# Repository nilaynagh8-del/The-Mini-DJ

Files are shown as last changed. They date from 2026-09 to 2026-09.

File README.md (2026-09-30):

# The-Mini-DJ
A small, portable, MIDI keyboard to make beats on the go.

*(or just a cooler way to make some beats)* 


---

## Quick Start

1. Download this repo and open the `firmware` folder.
2. Hold **BOOTSEL** and plug in the Pico — a drive called `RPI-RP2` appears.
3. Run `install.ps1` (right-click → Run with PowerShell). It flashes CircuitPython,
   then waits for the `CIRCUITPY` drive and copies all the code on automatically.
34. Plug it back in and make some sound.

---

## Features

- **2 Rotary encoders and button** for parameter adjustments.
- **12 keys** to make beats
- **2 sliders** to make additional parameter adjustments
- **LEDs** for some disco
- **Standalone beat machine** — 16-step sequencer, 6 patterns, runs on battery, no computer
- **3 key layouts** (piano / mirror / drums) with on-screen switching
- **Arpeggiator** with rate & direction controls
- **2 rotary encoders** (pushable) + **2 sliders**, all remappable on the fly
- **1.8" color display** with live view of keys, sliders, and layout
---

## Defaults (if you don't want to change anything):

### Keys for left set:

| Row | Key 1 | Key 2 | Key 3 | 
|---|---|---|---|
| **Top** | PIANO: C3 (48) · MIRROR: C3 · DRUMS: C3 | PIANO: C#3 (49) · MIRROR: D3 · DRUMS: D3  | PIANO: D3 (50) · MIRROR: E3 · DRUMS: E3 |
| **Bottom** | PIANO: D#3 (51) · MIRROR: F3 · DRUMS: F3 | PIANO: E3 (52) · MIRROR: G3 · DRUMS: G3  | PIANO: F3 (53) · MIRROR: A3 · DRUMS: A3 |

### Keys for right set:

| Row | Key 1 | Key 2 |
|---|---|---|
| **Row 1**  | PIANO: F#3 (54) · MIRROR: C4 · DRUMS: Kick (36, ch10) | PIANO: G3 (55) · MIRROR: D4 · DRUMS: Snare (38, ch10)  | 
| **Row 2**  | PIANO: G#3 (56) · MIRROR: E4 · DRUMS: Closed Hat (42, ch10) | PIANO: A3 (57) · MIRROR: F4 · DRUMS: Open Hat (46, ch10) |
| **Row 3**  | PIANO: A#3 (58) · MIRROR: G4 · DRUMS: Clap (39, ch10) | PIANO: B3 (59) · MIRROR: A4 · DRUMS: Tom (45, ch10) | 

### Left Encoder:

- **Rotate** → Octave shift (−2 to +6, shown on screen)
- **Push ×1** → Panic / all-notes-off
- **Push ×2** → Enter Beat Mode (standalone drum machine)
- **Push ×3** → Arpeggiator page (hold keys + it plays them for you)
- In Beat Mode: rotate = step cursor · hold + rotate = switch pattern A–F · hold 600 ms = clear pattern · tap = exit & save

### Right Encoder:

- **Rotate** → Sends the selected MIDI CC (default: CC 74 filter cutoff)
- **Push ×1** → Cycle CC target: Cutoff (74) → Mod (1) → Volume (7) → Expression (11) → Reverb (91)
- **Push ×2** → CC Remap page (move a slider to reassign its CC)
- **Push ×3** → Switch key layout (screen animation confirms)
- In Beat Mode: rotate = BPM (40–220) · push = play/stop

### Bottom Slider:

- **Slide** → CC 1 (Mod Wheel) by default — remappable to any CC 0–127 via the remap page. In Beat Mode: BPM macro.

### Top Slider:

- **Slide** → CC 7 (Channel Volume) by default — remappable. In Beat Mode: headphone/output volume.

---

## What is this?

This is a MIDI keyboard I made to get into music production. This device can make all kinds of music. You can make various beats, change up different audio affects, and more!

## How it works and Issues I Faced

The Raspberry Pi Pico is placed on the bottom of the PCB along with the switch, battery charging module, battery, and the DAC. The rest of the components are on the top. This MIDI keyboard is running **Circuit python** and uses many different libraries to make the various parts work. Pretty obvious, but it uses the keys use a matrix layout.

When I was designing the PCB I wanted to make this MIDI keyboard as versatile and portable as possible. I also wanted to make it look clean and sleek. I had to reposition the components several times before I was satisfied. I also spent quite some time in CAD designing this case as I wanted to make it as clean as possible. It took me quite some while to find the right shape and and size without making it look awkward. It was quite a challenge connecting all the desired components to the Pi Pico as it only had so many pins. I ended up having to interpret different methods to save pins.

## How to use in detail

Flash the firmware with install.ps1 (hold BOOTSEL while plugging in when prompted), then plug into any DAW — it appears as a standard USB MIDI keyboard and the 12 keys play notes immediately (velocity fixed at 100; the PCB has no velocity sensing). The screen shows a live view: layout name, octave, keys lighting up as you press, slider positions, encoder values, and arpeggiator status. The left encoder shifts octave (−2…+6), single-push is a panic button, double-push enters the standalone beat machine (6 synthesized drums over the I2S header into a PCM5102 — 16-step sequencer, 6 pattern slots, finger-drumming on the left keys, all persisted to flash, runs from battery with no computer), and triple-push opens the arpeggiator (rate 1/4–1/16, up/down/updown). The right encoder is an assignable macro control — single-push cycles what it sends (cutoff → mod → volume → expression → reverb), double-push opens the CC remap page where moving a slider live-reassigns which CC it transmits, and triple-push switches the key layout (PIANO chromatic run / MIRROR octaves / DRUMS + GM drum map) with a full-screen animation. Every setting — layout, octave, CC assignments, arp config, beats, BPM — saves to flash automatically and survives power-off. To adjust behavior, edit lib/md_kbd/config.py (pins, CC targets, debounce, slider deadband, screen offsets) and lib/md_kbd/layouts.py (base note, key→note maps, LED order), save to the CIRCUITPY drive, and it reboots with your changes; the serial console at code.circuitpython.org shows any errors.

---

## BOM

- 1x Raspberry PI Pico with headers
- 14x through-hole 1N4148 Diodes
- 12x MX-Style switches
- 2x EC11 Rotary encoder
- 1.8 Inch TFT LCD Screen Display *(GND, VCC, SCL, SDA, RES, DC, CS, BL)*
- 12x blank DSA keycaps
- 4x M3x11mm screws
- Adafruit PCM5100 I2S DAC breakout
- 14x SK6812MINI-E mini LEDs
- 2x Bourns PTA2043-2210DPB103 slide potentometer
- TP4056 Type-c USB Battery Charger Module
- 3000 MAH lipo 1s battery
- SS12D00 Mini Slide Switch

| Parts | Price |
|---|---|
| **1x [Raspberry PI Pico with headers](https://www.sparkfun.com/raspberry-pi-pico-2-with-headers.html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)**  | $6.60 |
| **14x [through-hole 1N4148 Diodes](https://www.sparkfun.com/diode-small-signal-1n4148.html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)**  |$3.50 |
| **12x [MX-Style switches](https://www.amazon.com/GATERON-Yellow-Keyboard-Switches-Mechanical/dp/B0DYJVRB46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)**  | $9.99 |
| **2x [EC11 Rotary encoder](https://www.sparkfun.com/rotary-encoder-illuminated-rgb.html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)**  | $9.90 |
| **1x [1.8 Inch TFT LCD Screen Display *(GND, VCC, SCL, SDA, RES, DC, CS, BL)](https://www.amazon.com/JESSINIE-Display-Arduino-128x160-Interface/dp/B0D31BGJWF)**  | $9.95 |
| **12x [blank DSA keycaps](https://www.sparkfun.com/cherry-mx-keycap-r2-opaque-black.html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)**  | $12.6 |
| **2x [Bourns PTA2043-2210DPB103 slide potentometer](https://www.mouser.com/ProductDetail/Bourns/PTA2043-2210DPB103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)**  | $3.92 |
| **1x [TP4056 Type-c USB Battery Charger Module](https://www.amazon.com/TP4056-Lithium-Charging-Protection-Functions/dp/B0G2S8478G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)**  | $3.90 |
| **1x [3000 MAH lipo 1s battery](https://www.amazon.com/JLJLUP-Rechargeable-Integrated-Protection-Development/dp/B0FH9XHXRT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)**  | $9.99 |
| **1x [SS12D00 Mini Slide Switch](https://www.sparkfun.com/spdt-slide-switch.html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)**  | $0.95 |
| **Total not including PCB or 3d prints:** | **$71.30** |

---

## Renders/Images






---

## Credits

Big shout out to **Hack Club** for giving me the opportunity to make this macropad. I would also like to thank [Logan Peterson](https://github.com/SharKingStudios/SplashPad/tree/main), as I modeled my readme.md after his hackpad's since I was amazed by how well written it was.

---

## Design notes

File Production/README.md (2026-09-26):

# MIDI Keyboard Firmware (CircuitPython 10.3.1)

Firmware for the custom 12-key MIDI keyboard PCB (RP2040 / Raspberry Pi Pico).
USB MIDI controller **and** a standalone pocket beat machine.

## What it does

| Control | Function |
|---|---|
| **12 keys** | Play notes (velocity fixed at 100). Three layouts, switch by **triple-pressing the right encoder**: PIANO / MIRROR / DRUMS |
| **Left encoder** | Turn = octave shift (−2…+6). Push = panic (all notes off). **Double-push = arpeggiator page** |
| **Right encoder** | Turn = assignable CC (cycles CUTOFF→MOD→VOLUME→EXPRESSION→REVERB on single push). **Double-push = CC remap page** |
| **Right encoder triple push** | Switch key layout (screen animation confirms) |
| **Bottom slider (RV1)** | CC 1 (mod wheel) by default, remappable |
| **Top slider (RV2)** | CC 7 (channel volume) by default, remappable |
| **Encoder pushes** | Both wired into the key matrix — they also light their SK6812 LEDs |
| **14× SK6812** | Keys glow while held (hue = note), sliders mirror position, encoders show value |
| **240×240 LCD** | Live view: layout, octave, key grid lighting up, slider bars, encoder values, arp status, USB status |

Layouts:
- **PIANO** — continuous chromatic run starting at C3 (MIDI 48), left block then right block
- **MIRROR** — right block repeats the left block one octave up (great for octave stabs)
- **DRUMS** — left block notes, right block General MIDI drum map on channel 10

Everything (layout, octave, CC assignments, arp settings) **saves to flash** automatically when you leave a settings page — survives power-off.

## Install (one click)

1. Double-click `install.ps1` (or right-click → Run with PowerShell)
2. Follow the prompts: unplug, hold **BOOTSEL**, replug, release
3. The script flashes CircuitPython and copies everything to `CIRCUITPY`
4. Done — your keyboard appears as a USB MIDI device

The script can be re-run anytime to update the firmware files (skip to the CIRCUITPY step — CircuitPython is already installed).

## Manual install

1. Hold BOOTSEL while plugging in USB → `RPI-RP2` drive appears
2. Drag `firmware/adafruit-circuitpython-raspberry_pi_pico-en_US-10.3.1.uf2` onto it
3. Board reboots as `CIRCUITPY`
4. Copy `lib/`, `code.py`, `boot.py` from this folder onto `CIRCUITPY`

## Playing it

- Plug into any DAW (Ableton, FL, GarageBand…) — it shows up as a standard USB MIDI keyboard
- Hold keys and use the DAW's learn function to map the sliders/encoders
- **Arpeggiator**: triple-push the *left* encoder. L-enc selects ON/OFF, RATE, MODE; R-enc changes the selected value; right-push exits (and saves)

## 🥁 Beat mode (standalone, no computer)

Turn your keyboard into a pocket drum machine: 6 synthesized drums through
the I2S header → PCM5102 DAC → headphones.

| Gesture | Action |
|---|---|
| **Double-push LEFT encoder** | Enter/exit beat mode |
| Right-block keys (6) | Toggle drum hit at the step cursor (and audition it) |
| Left-block keys (6) | Whack the drums live, finger-drumming style |
| Left encoder | Move the step cursor (1-16) |
| Right encoder | BPM 40-220 |
| Bottom slider | BPM macro |
| Top slider | Output volume |
| Right-encoder push | Play / stop |
| Left-encoder tap | Exit beat mode (saves) |
| Left-encoder hold 600 ms | Clear current pattern |

6 pattern slots (A-F) × 16 steps × 6 lanes, all saved to flash. Step cursor
is the yellow column; the white column sweeping is the playhead.

## 🔋 Battery power

You need: a 3.7 V LiPo/Li-Ion (or 4×AA pack, 4.5-5.5 V) + a small slide
switch + a PCM5102 DAC module (~$3).

Wiring:
- Battery **+** → one leg of the switch → Pico **VSYS** (pin 39)
- Battery **–** → Pico **GND** (pin 38)
- PCM5102: **VIN→3V3 (pin 36)**, **GND→GND**, **BCK→GP15**, **LRCK/LCK→GP16**, **DIN→GP17**, **SCK→GND** (tie the SCK jumper on the module), **3.3V logic jumper open**
- Headphones: 3.5mm jack on the PCM5102 module's L/R/G

USB and battery can both be connected — the Pico's power path IC handles it
(USB wins when present). The switch simply disconnects the battery.

Beat mode lazily initializes audio the first time you use it, so MIDI-only
sessions pay zero memory cost.

## Tuning / troubleshooting

| Symptom | Fix |
|---|---|
| Screen shows shifted/mirrored image | Edit `LCD_X_OFFSET` / `LCD_Y_OFFSET` in `lib/md_kbd/config.py`, or set MADCTL rotation (see lcd.py) |
| Screen stays black | Check LCD solder joints; try lowering `LCD_SM_FREQ` in config.py (e.g. `31_250_000`) |
| Wrong key plays | Swap entries in `HW_BITS` in `lib/md_kbd/layouts.py` |
| LED #N lights the wrong key | Swap entries in `LED_CHAIN2KEY` in `layouts.py` |
| Encoder counts backwards | Swap the A/B pin numbers in `config.py` (`ENC_*_A` / `ENC_*_B`) |
| Slider jitters | Raise `SLIDER_DEADBAND` in config.py |
| Serial console | `code.circuitpython.org` in a browser, or Mu editor — errors print there |

## Source layout

```
code.py                    entry point
boot.py                    USB bring-up (kept minimal)
lib/md_kbd/
  config.py                pins, timing, CC targets (from your KiCad netlist)
  layouts.py               key layouts + hardware-bit ↔ physical mapping
  matrix.py                2×7 debounced matrix scan
  encoders.py              rotaryio quadrature readers
  sliders.py               oversampled ADC with hysteresis
  leds.py                  SK6812 patterns
  lcd.py                   ST7789 driver (PIO-SPI) + framebuffer + 5×7 font
  ui.py                    all screen pages + layout animation
  arp.py                   arpeggiator engine
  midi_io.py               USB MIDI packet sender
  settings.py              flash-persisted settings (NVM)
  app.py                   main state machine
```

## Future: standalone synth

The PCB has an I2S header (GP15/16/17) ready for a PCM5102 DAC module. That's a v2 feature — sound generator so the keyboard makes noise with no computer attached.

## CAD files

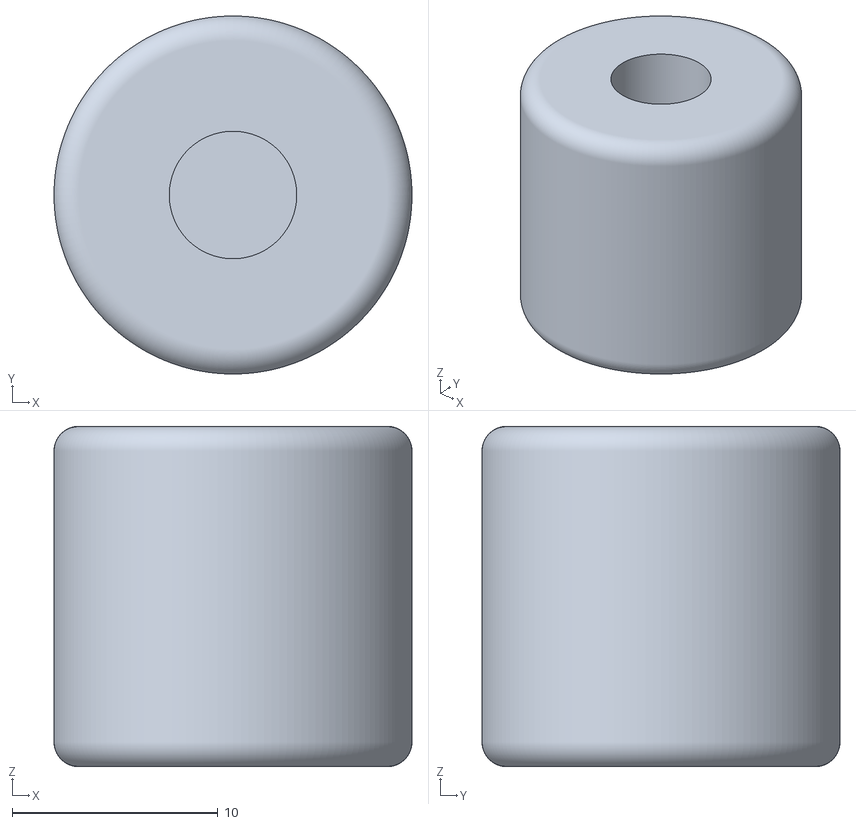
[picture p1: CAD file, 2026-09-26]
Production/Knob (1).stl
17.4 x 17.4 x 16.6

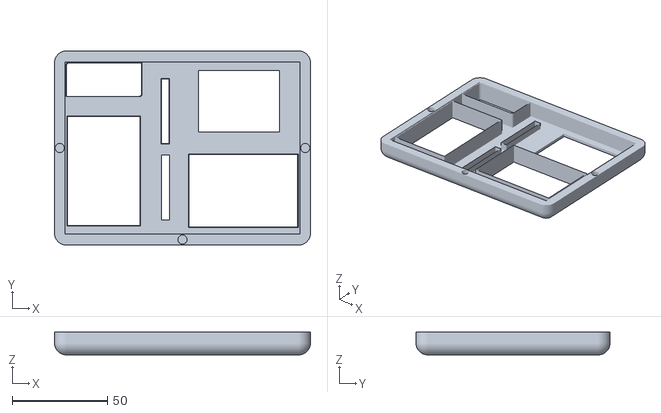
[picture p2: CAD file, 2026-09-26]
Production/Top Case.stl
134.5 x 102.0 x 12.0

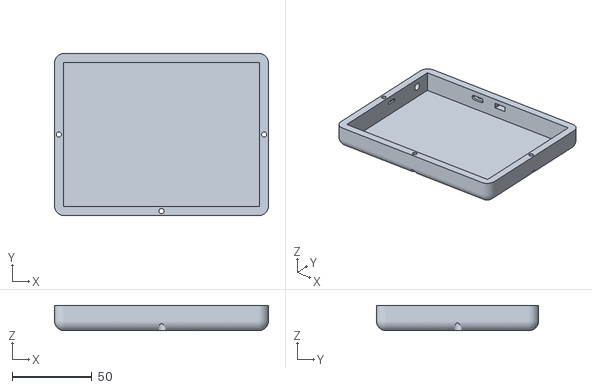
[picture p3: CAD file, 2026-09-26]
Production/Bottom Case.stl
134.5 x 102.0 x 16.0

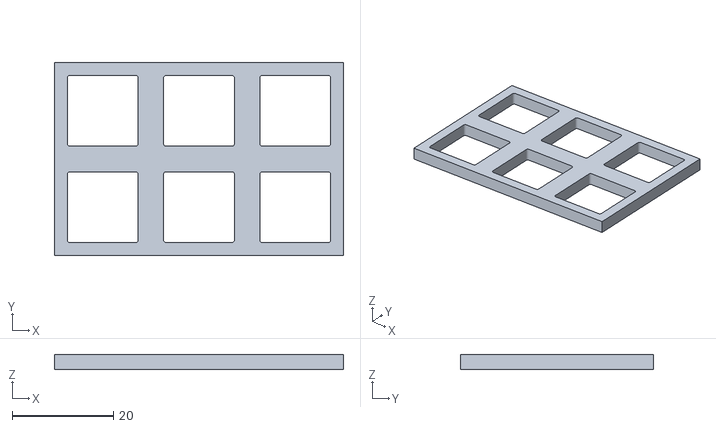
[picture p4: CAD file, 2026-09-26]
Production/Key Plates.stl
57.1 x 38.1 x 3.00

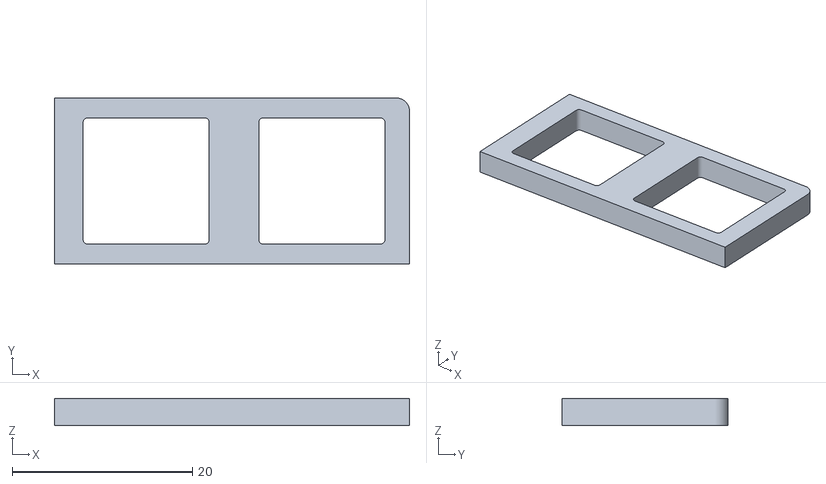
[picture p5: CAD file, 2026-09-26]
Production/Rotary Knobs Plate.stl
39.4 x 18.4 x 3.00

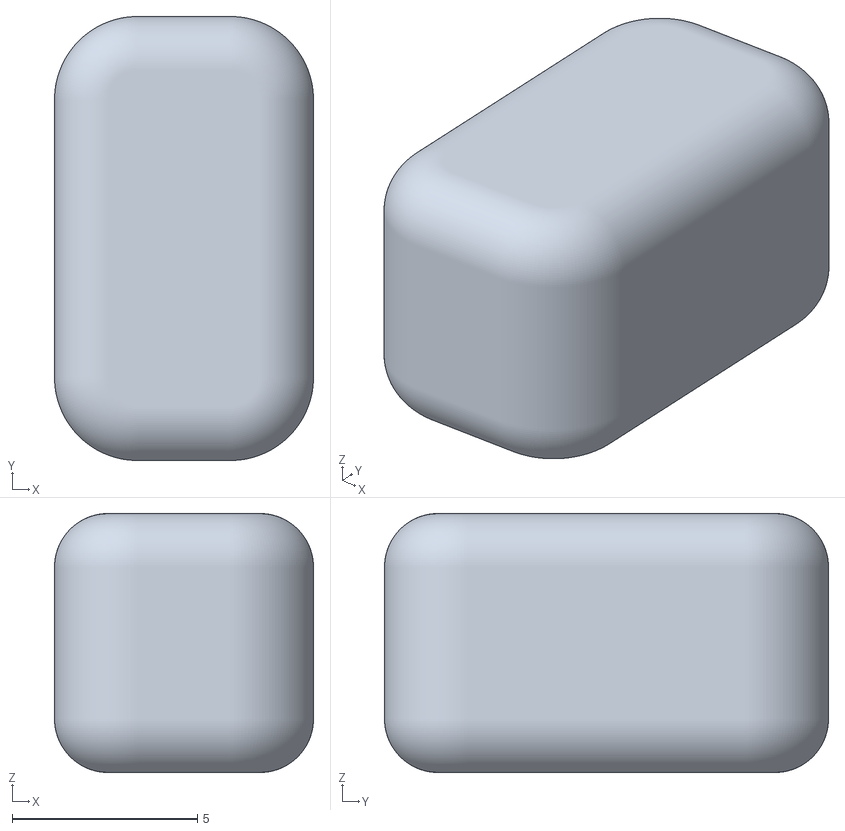
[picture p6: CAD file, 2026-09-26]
Production/Slider tab.stl
7.00 x 12.0 x 7.00

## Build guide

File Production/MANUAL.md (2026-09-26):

# MIDI Keyboard — Complete Manual

*How everything works and how to use it. Written for someone who has never
touched MIDI before.*

---

## Table of Contents

1. [What you built](#1-what-you-built)
2. [MIDI in 5 minutes](#2-midi-in-5-minutes)
3. [Installing the firmware](#3-installing-the-firmware)
4. [Powering the keyboard](#4-powering-the-keyboard)
5. [Using it — Performance mode](#5-using-it--performance-mode)
6. [Using it — Settings pages](#6-using-it--settings-pages)
7. [Using it — Beat mode (standalone drums)](#7-using-it--beat-mode-standalone-drums)
8. [How the code works](#8-how-the-code-works)
9. [Hardware reference — how the PCB works](#9-hardware-reference--how-the-pcb-works)
10. [Customizing](#10-customizing)
11. [Troubleshooting](#11-troubleshooting)

---

## 1. What you built

A 12-key USB MIDI controller **and** standalone drum machine:

| Part | What it is |
|---|---|
| 12 mechanical keys | Play notes (or drums) |
| 2 rotary encoders (left, right) | Turn = adjust · push = button (with tap/double/triple press) |
| 2 sliders (bottom RV1, top RV2) | Analog control of any MIDI CC |
| 240×240 color LCD | Live status: notes, sliders, encoders, playhead |
| 14 RGB LEDs | Under-key glow + 2 encoder LEDs |
| I2S header (J2) | Where the PCM5102 DAC plugs in for beat mode |
| Pico (RP2040) | The brain, runs CircuitPython |

Two power sources: **USB** (data + power) or **battery** (power only, via
your switch into VSYS). Both at once is fine — USB wins.

---

## 2. MIDI in 5 minutes

MIDI is just small text-like messages sent over USB. The ones this keyboard
sends:

| Message | Meaning | When we send it |
|---|---|---|
| **Note On** (note number, velocity) | "a key went down" | You press a key. Note 60 = middle C. Velocity = how hard (ours is fixed 100) |
| **Note Off** | "key came up" | You release |
| **Control Change** (CC#, value 0–127) | "a knob/slider moved" | You turn an encoder or move a slider. CC 1 = mod wheel, CC 7 = volume, CC 74 = filter cutoff — these are standard numbers synths already understand |
| **CC 123, value 0** | "all notes off" (panic) | Left-encoder single push |

Your DAW (Ableton, FL Studio, GarageBand, Reaper…) receives these and makes
sound with whatever instrument is selected. **The keyboard makes no sound by
itself** — it's a controller. Except in beat mode, where it synthesizes its
own drums.

---

## 3. Installing the firmware

### Easy way

1. Plug the Pico in (it's the big chip on your PCB — it's a Raspberry Pi Pico module).
2. Double-click `install.ps1` → "Run with PowerShell".
3. When it says so: unplug, **hold the BOOTSEL button**, plug back in, release.
4. Wait. Done.

The installer flashes CircuitPython (the interpreter) once, then copies the
firmware files. To update your own edits later, re-run it — the flash step
is skipped since CircuitPython is already on the chip.

### Manual way

1. Hold **BOOTSEL**, plug in USB, release → a drive `RPI-RP2` appears.
2. Drag `firmware/adafruit-circuitpython-raspberry_pi_pico-en_US-10.3.1.uf2` onto it.
3. Board reboots as `CIRCUITPY`.
4. Copy `code.py`, `boot.py`, and the `lib/` folder onto `CIRCUITPY`.

### Seeing errors

Open [code.circuitpython.org](https://code.circuitpython.org) in Chrome/Edge,
click "Serial" — or use the Mu editor. If something's wrong with the code,
the error prints there.

---

## 4. Powering the keyboard

### USB only (no battery needed)

Everything works, including beat mode if a DAC is connected.

### Battery + switch (portable)

You need: 3.7 V LiPo/Li-Ion or 4×AA pack (4.5–5.5 V), any small slide
switch, optional PCM5102 DAC for sound.

```
Battery (+) ──► switch ──► Pico VSYS (physical pin 39, back row)
Battery (–) ─────────────► Pico GND  (physical pin 38)
```

- Flip the switch → keyboard boots, octave LEDs flash, screen shows "MIDI".
- Plugging USB while the switch is on: safe, USB takes over.
- **Never** connect a battery straight to the 3V3 pin — VSYS only.

### Sound for beat mode (PCM5102, ~$3)

```
PCM5102   →   Pico
VIN       →   3V3  (pin 36)
GND       →   GND
BCK       →   GP15
LCK       →   GP16
DIN       →   GP17
SCK       →   GND  (also solder the SCK jumper pad on the module)
```

Headphones plug into the DAC module's own 3.5 mm jack. Volume is the top
slider while in beat mode.

---

## 5. Using it — Performance mode

This is the main screen after boot. Just play.

### Keys

Press → note plays, key lights up on the screen grid and on the PCB's LED.
Release → stops. You can hold as many as you want (N-key rollover).

**Three layouts** — switch with **triple-push of the right encoder** (screen
bursts a ring animation + name):

| Layout | Left block (6 keys) | Right block (6 keys) |
|---|---|---|
| **PIANO** | C3, D3, E3, F3, G3, A3 … continues chromatically → | …A#3 up to G#4 |
| **MIRROR** | C3 D3 E3 F3 G3 A3 | same + one octave up |
| **DRUMS** | notes C3–A3 | GM drum map (channel 10): kick, snare, hats, etc. |

### Left encoder

| Gesture | Action |
|---|---|
| Turn | Octave shift −2…+6 (shown top-left of screen) |
| Push ×1 | **Panic** — all notes off (red LED flash) |
| Push ×2 | Enter **beat mode** |
| Push ×3 | Enter **arpeggiator page** |

### Right encoder

| Gesture | Action |
|---|---|
| Turn | Sends the selected CC (default CC 74 cutoff) |
| Push ×1 | Cycle which CC it controls: CUTOFF → MOD → VOLUME → EXPR → REVERB |
| Push ×2 | Enter **CC remap page** |
| Push ×3 | Switch layout (PIANO → MIRROR → DRUMS) |

### Sliders

- Bottom (RV1) = **CC 1, mod wheel**
- Top (RV2) = **CC 7, channel volume**

The DAW responds automatically — no mapping needed for these two.

---

## 6. Using it — Settings pages

### CC Remap page (double-push RIGHT encoder)

Screen shows both sliders with their current CC number. **Move a slider** —
it now sends that number as you drag? No: moving a slider *changes* which CC
it sends (the number follows your position 0–127, pick one you like, e.g.
CC 74 for cutoff, CC 71 for resonance, CC 2 for breath). **Push right
encoder** to save and go back. Everything is stored in flash and remembered
after power-off.

### Arpeggiator page (triple-push LEFT encoder)

Hold some keys, and the arp plays them as a repeating pattern for you.

| Row | Turn RIGHT encoder to change |
|---|---|
| ON/OFF | enable/disable |
| RATE | 1/4, 1/8, 1/8T (triplet), 1/16 |
| MODE | UP, DOWN, UPDOWN |
| EXIT | — (or just push RIGHT encoder) |

LEFT encoder moves the yellow selection. Leaving the page saves settings.

### Beat mode

→ next section.

---

## 7. Using it — Beat mode (standalone drums)

**Enter: double-push LEFT encoder.** Screen becomes a 16-step grid. This is
a real drum machine that runs on battery, no computer.

### What's on screen

- Top: pattern letter (A–F), BPM, play indicator (green = playing)
- Middle: 6 rows (lanes) × 16 steps. Row = drum sound, column = time.
  Lit cell = drum fires when the playhead crosses that column.
- **White column** = playhead (where we are now)
- **Yellow outline** = cursor (the step you're editing)

| Lane | Sound |
|---|---|
| KCK | kick drum |
| SNR | snare |
| CLP | clap |
| HHC | closed hi-hat (short) |
| HHO | open hi-hat (rings out) |
| TOM | tom |

### Making your first beat

1. Double-push LEFT encoder → grid appears.
2. Turn LEFT encoder to move the yellow cursor to step 1.
3. Tap right-block keys to toggle drums at that step: key 1 = kick lane,
   key 2 = snare, key 3 = clap, key 4 = HHC, key 5 = HHO, key 6 = tom.
   (It auditions the sound as you toggle — headphones on!)
4. Move cursor to step 5, add a snare. Step 9: kick again. Classic.
5. Push RIGHT encoder → **plays**. Push again → stops.
6. Whack the left-block keys anytime — live finger-drumming on top.

### Controls while in beat mode

| Control | Action |
|---|---|
| LEFT encoder | Move step cursor 1–16 |
| RIGHT encoder | BPM 40–220 |
| Bottom slider | BPM macro (sweep to feel it) |
| Top slider | Volume |
| RIGHT push | Play / stop |
| LEFT hold + LEFT-encoder turn | Switch pattern slot A–F |
| LEFT tap | Exit beat mode (saves everything) |
| LEFT hold ~600 ms | Clear current pattern |

### Patterns

Six slots A–F, all saved to flash and reloaded at boot:

- **Hold LEFT-encoder push + turn LEFT encoder** → switches between slots
  A→B→C→D→E→F→A… The pattern letter in the top-left corner shows where you
  are. The play/stop state keeps going — swap patterns live mid-groove.
- **Hold LEFT push ~600 ms** → clear the current slot (all cells off).

### Battery life

RP2040 + LCD + LEDs ≈ 100–150 mA. A 2000 mAh LiPo runs ~13–20 hours.

---

## 8. How the code works

```
CIRCUITPY/
├── boot.py            ← runs first: keeps USB + serial console alive
├── code.py            ← entry point, calls md_kbd.app.run()
└── lib/md_kbd/
    ├── config.py      ← every pin number + timing constant
    ├── util.py        ├── gp(): GPIO number → Pin object
    ├── settings.py    ← keyboard settings in flash (NVM, offset 0)
    ├── layouts.py     ← key→note maps + hardware-bit→physical position
    ├── matrix.py      ← scans 14 switches (12 keys + 2 encoder pushes)
    ├── encoders.py    ← rotation tracking (hardware quadrature)
    ├── sliders.py     ← ADC reads with noise filtering
    ├── leds.py        ← SK6812 patterns (hue per note, slider mirror)
    ├── lcd.py         ← ST7789 driver + drawing + 5×7 font (PIO-SPI!)
    ├── ui.py          ← every screen (perf, remap, arp, beat, animation)
    ├── arp.py         ← arpeggiator engine
    ├── audio.py       ← drum synthesis + sequencer + flash patterns
    ├── midi_io.py     ← USB MIDI packet sender
    └── app.py         ← the brain: ties everything together
```

### The main loop (app.py `run()`)

Runs forever, ~500 times a second:

1. **Scan the matrix** — one row low at a time, read 7 columns; debounce.
2. **Scan encoders** — rotation deltas become octave/CC/BPM changes.
3. **Poll the arpeggiator** — fire scheduled notes.
4. **Poll sliders** every 15 ms — emit CC only if value moved ≥ 3 counts.
5. **Handle pushes** — tap/double/triple gesture state machine.
6. **Redraw UI** if dirty and ≥ 60 ms since last draw (never blocks keys).
7. **Render LEDs** every 40 ms.
8. **In beat mode**: poll the sequencer, which schedules drum hits against
   a monotonic clock — timing never drifts even if drawing hiccups.

### The clever bits

- **PIO-SPI screen** — GP21 (MOSI) can't do hardware SPI on RP2040, so a
  2-instruction PIO state machine shifts pixels at ~21 Mbit/s. Faster than
  bit-banging, and leaves SPI0 free.
- **N-key rollover** — every key has a diode, so simultaneous presses are
  all detected distinctly.
- **Lazy audio** — drum samples (~100 KB) only exist while beat mode is
  active; entering MIDI-only costs zero RAM.
- **NVM layout** — keyboard settings at offset 0 (32 B), beat patterns at
  offset 1024 (~600 B). Proven non-overlapping.
- **Gesture engine** — pushes are counted in a 450 ms window, dispatched
  once, so 1×/2×/3× presses never mis-fire.
- **Hysteresis sliders** — an untouched pot never spams the DAW with
  jittery CC values.

---

## 9. Hardware reference — how the PCB works

Every pin, verified from your KiCad netlist:

| Pico GPIO | Connected to |
|---|---|
| GP0, GP1, GP3, GP4, GP5, GP6 | matrix columns 1–5 + col 7 (SW6/SW12) |
| GP2 | matrix "encoder" column (SW13/SW14 pushes) |
| GP7, GP8 | matrix rows 3, 4 (driven low one at a time) |
| GP9 | SK6812 LED data (14 LEDs in a chain) |
| GP10, GP11 | right encoder A/B (SW13) |
| GP12, GP13 | left encoder A/B (SW14) |
| GP14 | LCD reset |
| GP15, GP16, GP17 | I2S to DAC: BCK / LRCK / DIN |
| GP18, GP21 | LCD SPI: SCK / MOSI (PIO bit-banged) |
| GP19, GP22 | LCD CS / DC |
| GP20 | LCD backlight |
| GP26/ADC0 | bottom slider RV1 |
| GP27/ADC1 | top slider RV2 |

### Matrix map (which bit = which key)

14 switches on 2 rows × 7 columns. Bit = row×7 + col:

| Bit | Key | Physical position |
|---|---|---|
| 0, 7 | SW4, SW10 | left block top: middle, right |
| 6, 0, 7 | left block top L→R: SW6, SW4, SW10 | |
| 13, 1, 8 | left block bottom L→R: SW12, SW5, SW11 | |
| 2, 3, 4 | right block column 1: SW1 top, SW2 mid, SW3 bottom | |
| 9, 10, 11 | right block column 2: SW7 top, SW8 mid, SW9 bottom | |
| 5 | SW13 push | **right encoder push** |
| 12 | SW14 push | **left encoder push** |

(The `layouts.py` `HW_BITS` tuple encodes exactly this — edit it there if a
key feels wrong.)

### LED chain order

From the PCB: `#0 = first LED the data pin reaches (D7)` then winds through
the board. `layouts.py` `LED_CHAIN2KEY` maps chain position → the 12 keys;
`LED_ENC_CHAIN = (13, 12)` are the two encoder LEDs (left, right).

---

## 10. Customizing

All the fun stuff is in `lib/md_kbd/config.py`:

```python
MIDI_CHANNEL = 0        # 0-15 → drums typically want 9
ENC_CC_TARGETS = (74, 1, 7, 11, 91)   # right-encoder CC cycle
ENC_CC_NAMES = ("CUTOFF", "MOD", "VOLUME", "EXPRS", "REVERB")
LCD_X_OFFSET = 0        # image shifted? try 2 or 3
LCD_Y_OFFSET = 0
LCD_SM_FREQ = 62_500_000  # lower to 31_250_000 if screen is flaky
SLIDER_DEADBAND = 3     # raise if sliders jitter
DEBOUNCE_MS = 10        # raise if keys double-fire
```

**Base note / octave range**: `layouts.py` → `BASE = 48` (C3). Try 36 or 60.

**Drum sounds**: `audio.py` → `DRUMS` tuple (GM note numbers) and the
`_kick()`, `_snare()` etc. functions to reshape the synthesis.

**Colors / layout of the screen**: `ui.py` constants at the top.

After any edit: save the file onto `CIRCUITPY` — it reboots and runs it.
Break something? Delete `code.py`'s import and the board shows a safe error
on the serial console; restore from this folder.

---

## 11. Troubleshooting

| Symptom | Fix |
|---|---|
| Screen black | Check LCD solder; lower `LCD_SM_FREQ`; check backlight pin |
| Screen image shifted | `LCD_X_OFFSET` / `LCD_Y_OFFSET` in config.py |
| Wrong key plays | Swap entries in `HW_BITS` (layouts.py) |
| LED lights wrong key | Swap entries in `LED_CHAIN2KEY` (layouts.py) |
| Encoder counts backwards | Swap the A/B pins in config.py |
| Keys double-fire | Raise `DEBOUNCE_MS` to 15–20 |
| Sliders jitter in DAW | Raise `SLIDER_DEADBAND` |
| No USB MIDI device | Re-run installer; try cable that carries data |
| Beat mode silent | Check DAC wiring; top slider up; SCK jumper on module |
| Beat mode crackles | Normal for 8-bit lo-fi engine; lower volume |
| Board shows `CIRCUITPY` but no code runs | `code.py` has an error — check serial console |
| Stuck notes | Left-encoder single push = panic |

---

*Generated for Nilay's MIDI Keyboard — KiCad project "Midi Keyboard", rev 4
sheet, firmware v1.1.*

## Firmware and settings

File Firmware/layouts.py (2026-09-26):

# Key layouts and the hardware-bit -> physical position mapping.
#
# Hardware bit index = row*7 + col (see config.py). The physical panel:
#   left block is 3 columns x 2 rows, right block is 2 columns x 3 rows.
# HW_BITS[phys] = hardware bit index for physical key `phys`:
#   left block top L-to-R, left bottom L-to-R,
#   right block top-to-bottom column-major (2 wide x 3 tall).
HW_BITS = (
    # left block (0-5): top row then bottom row
    6, 0, 7,     # SW6, SW4, SW10   (top L->R)
    13, 1, 8,    # SW12, SW5, SW11  (bottom L->R)
    # right block (6-11): 2 cols x 3 rows, column-major (SW at x=181 then x=200)
    2, 3, 4,     # SW1 top, SW2 mid, SW3 bottom   (left column)
    9, 10, 11,   # SW7 top, SW8 mid, SW9 bottom   (right column)
)
# Encoder push bits (NOT in the physical map):
#   bit 5  = SW13 push = RIGHT encoder
#   bit 12 = SW14 push = LEFT encoder

BASE = 48  # C3

# 1) Piano: continuous chromatic run, left block then right block.
PIANO = tuple(BASE + i for i in range(12))

# 2) Mirrored: right block repeats left block one octave up.
_MIRROR_OFFS = (0, 2, 4, 5, 7, 9)
MIRROR = tuple(BASE + _MIRROR_OFFS[i % 6] + (12 if i >= 6 else 0)
               for i in range(12))

# 3) Left notes + right drum pads (General MIDI channel 10).
# kick, snare, closed hat, open hat, clap, low tom
DRUMS = (36, 38, 42, 46, 39, 45)
DRUM_CHANNEL = 9  # 0-based; GM drums = channel 10


def note_for(layout_id, phys_idx):
    """Return (midi_note, channel) for physical key 0..11."""
    if layout_id == 1:
        return MIRROR[phys_idx], 0
    if layout_id == 2:
        if phys_idx < 6:
            return PIANO[phys_idx], 0
        return DRUMS[phys_idx - 6], DRUM_CHANNEL
    return PIANO[phys_idx], 0


LAYOUT_NAMES = ("PIANO", "MIRROR", "DRUMS")

# LED chain position -> physical key (same 0-11 indexing).
LED_CHAIN2KEY = (6, 0, 3, 5, 2, 4, 1, 7, 10, 8, 11, 9)
LED_ENC_CHAIN = (13, 12)  # chain pos of left, right encoder LEDs

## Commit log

2026-09-26 Revise README with installation steps and BOM updates
    Updated installation instructions and added new features to the README. Adjusted BOM item counts and added new components.
2026-09-30 Add unzipped CAD file
